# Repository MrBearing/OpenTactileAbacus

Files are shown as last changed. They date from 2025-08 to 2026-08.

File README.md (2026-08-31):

# OpenTactileAbacus

A 3D-printable abacus designed for visually impaired users.

[日本語版README](README_jp.md) | [Thingiverse](https://www.thingiverse.com/thing:7402750) | [MakerWorld](https://makerworld.com/ja/models/3242916-opentactileabacus-ver-2026#profileId-3674481)

## Product Images

### 23-Digit Abacus

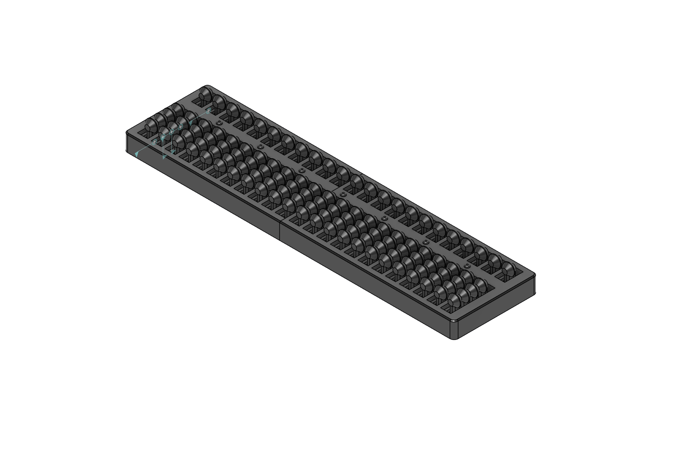
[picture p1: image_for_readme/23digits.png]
Completed 23-digit abacus

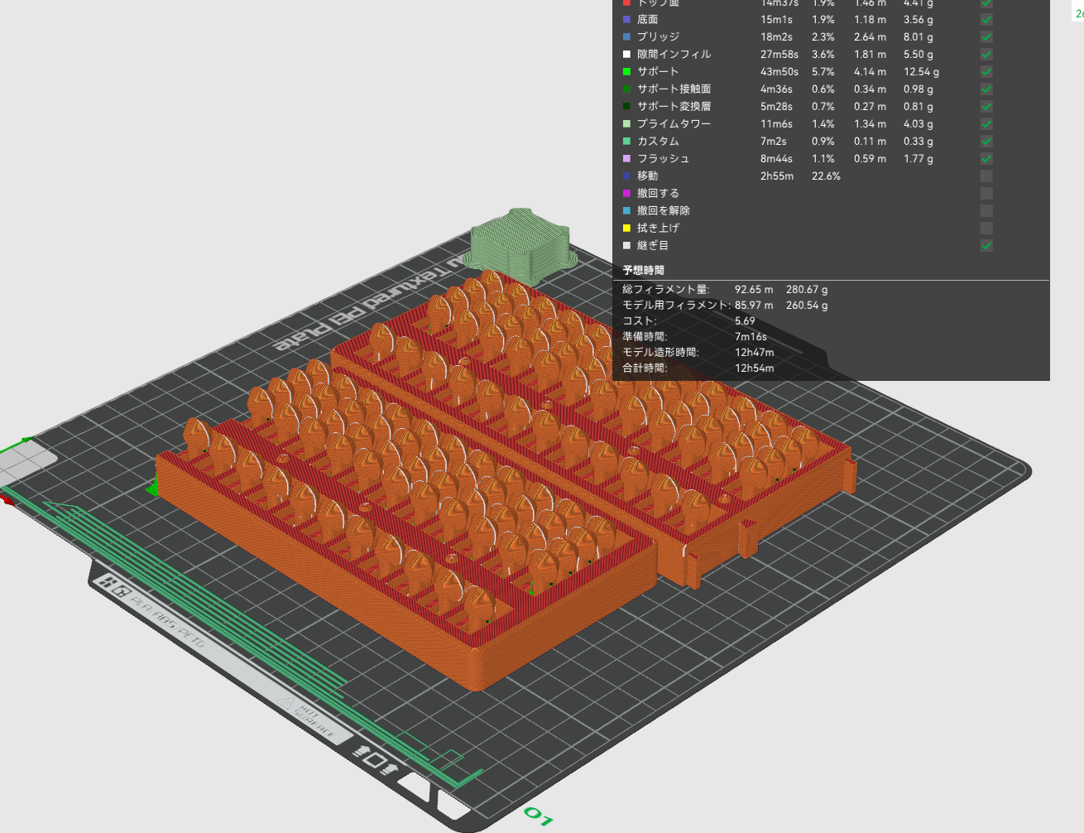
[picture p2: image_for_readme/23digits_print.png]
Printed 23-digit abacus


## Features

- **Tactile-Optimized Design**: Beads and frame designed for fingertip operation by visually impaired users
- **Print-in-Place Model**: The frame and beads are printed together, so the beads do not need to be installed separately
- **Split Frame**: Print the left and right frame sections and join their dovetail connectors to complete the abacus
- **3D-Printable**: Compatible with standard 3D printers

## File Structure

```
├── README.md              # English README (this file)
├── README_jp.md           # Japanese README
├── 3mf/
│   └── 23digits_abacus.3mf          # 23-digit abacus (3MF format)
├── autodesk_fusion/
│   ├── 23digits_abacus.f3z          # Source file (Fusion 360)
│   └── 23digits_abacus.step         # Exchange CAD file (STEP format)
└── stl/
    ├── 23digits_abacus_left.stl     # Left section of the 23-digit abacus (STL format)
    └── 23digits_abacus_right.stl    # Right section of the 23-digit abacus (STL format)
```

## Available Models

### 23-Digit Abacus

- **3MF File (Recommended)**: `3mf/23digits_abacus.3mf`
- **STL Files**:
  - `stl/23digits_abacus_left.stl`
  - `stl/23digits_abacus_right.stl`

### Source Files

Fusion 360 source files are provided for customization and improvement:

- `autodesk_fusion/23digits_abacus.f3z`
- `autodesk_fusion/23digits_abacus.step`

## Print Specifications

### Tested Print Environment

- **3D Printer**: Bambu Lab X1 Carbon
- **Other Compatible Printers**:
  - Standard FDM 3D printers with a 0.4 mm nozzle
  - Printers with a sufficient build volume

### Recommended File Format

- **3MF File (Recommended)**: Includes print settings and supports optimized for Bambu Lab printers
  - The included profile uses **Bambu Support For PLA/PETG as filament 2 for the support interfaces** and sets the top Z distance to `0 mm`. Map filament 2 to the specified support material and use an AMS or an equivalent multi-material setup.
  - Do not map both filament slots to the same PLA spool without first adding a removable interface gap; the zero-gap interfaces may bond to the print-in-place parts.
- **STL Files**: For other printers or custom slicer settings
  - **Important (Bambu Studio)**: Set **Slice gap closing radius** (`slice_closing_radius`) to `0.02 mm` before slicing

### Recommended Settings

- **Layer Height**: 0.2 mm
- **Infill**: 15–20%
- **Supports**: May be required (refer to the layout and settings in the 3MF file)
- **Print Time**:
  - 23-digit version: Approximately 12 hours (one build plate)
- **Filament Usage**:
  - 23-digit version: Approximately 280 g
- **Material**: PLA recommended (ABS and PETG are also supported)

Print time and filament usage are estimates based on the Bambu Lab X1 Carbon.

### Post-Processing

1. Carefully remove the support material.
2. Insert a flat-head screwdriver with an approximately 3 mm-wide tip into the hole at the bottom of each bead. Move the bead back and forth several times to break the bonds formed during printing.

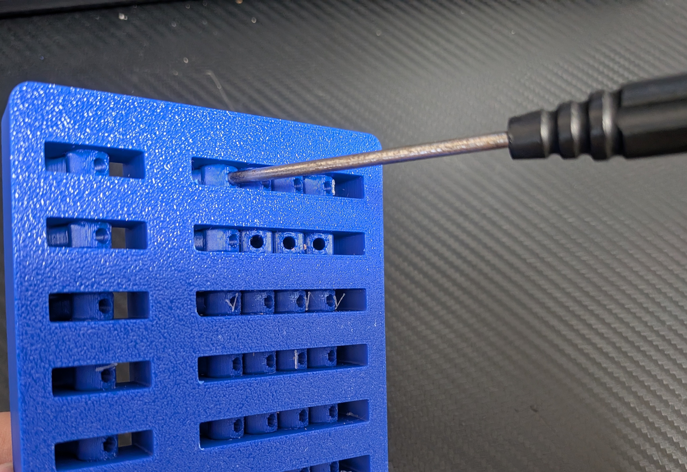
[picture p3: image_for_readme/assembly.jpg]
Using a flat-head screwdriver in the hole at the bottom of a bead to release print bonds
   

3. Check that each bead moves along its rod.
4. If a bead is tight, move it back and forth repeatedly to wear in the sliding surfaces. If it remains tight, lightly sand the rod.
5. Make sure all beads move smoothly and provide comfortable tactile operation for visually impaired users.

> **Caution**: Work carefully and do not apply excessive force, as the screwdriver could damage the printed parts or cause injury.

## Assembly Instructions

### Using the 3MF File (Recommended)

1. Open `3mf/23digits_abacus.3mf` in Bambu Studio and print the left and right sections.
2. Follow the post-processing instructions above to remove supports and release the beads.
3. Join the dovetail connectors on the left and right sections.
4. Confirm that every bead moves smoothly.

### Using the STL Files

1. Import `stl/23digits_abacus_left.stl` and `stl/23digits_abacus_right.stl` into your slicer.
2. If you use Bambu Studio, set **Slice gap closing radius** (`slice_closing_radius`) to `0.02 mm`.
3. Set an appropriate orientation and supports, then print both sections.
4. Follow the post-processing instructions above to remove supports and release the beads.
5. Join the dovetail connectors on the left and right sections.
6. Confirm that every bead moves smoothly and adjust as needed.

## Usage

### Basic Operation

1. Five-value bead (upper bead): Each bead represents 5.
2. One-value beads (lower beads): Each bead represents 1, with four beads per digit representing values up to 4.
3. Move the beads with your fingertips to represent numbers and perform calculations.

## Contributions and Improvements

Contributions to this project are welcome:

- **Issues**: Report bugs or suggest improvements
- **Pull Requests**: Submit design improvements or documentation updates
- **Discussions**: Share user feedback and examples of educational use

## Support and Contact

- **Issues**: Please use the GitHub Issues tab for questions and reports
  - Examples:
    - Requests for different size variations
    - Surface textures that improve tactile identification
    - Better assembly methods
    - Expanded educational guides

- **Discussions**: Exchange information through GitHub Discussions
- **Email**: takumi1988okamoto@gmail.com

## Credits

This project was created to support the education of visually impaired people and promote numeracy learning.

We hope it contributes to a more accessible society.

## Related Links

- [Thingiverse](https://www.thingiverse.com/thing:7402750)
- [MakerWorld](https://makerworld.com/ja/models/3242916-opentactileabacus-ver-2026#profileId-3674481)

## License

This work is licensed under the Creative Commons Attribution 4.0 International License (CC BY 4.0).

© 2025–2026 Takumi Okamoto

See the [LICENSE](LICENSE) file for details.
Please also read the [Disclaimer](DISCLAIMER.md) before use.

---

**We hope this project makes a meaningful contribution to the learning and daily lives of visually impaired people.**

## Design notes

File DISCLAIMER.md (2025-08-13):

# Disclaimer / 免責事項

## English

### General Disclaimer
The creator of OpenTactileAbacus assumes no responsibility for patent infringement, other intellectual property right infringement, product liability, or any other damages arising from the use of this data (including commercial use and modifications). Users are obligated to verify and comply with relevant laws, safety standards, and third-party rights at their own responsibility.

### Commercial Use Notice
Those engaging in commercial use should conduct independent patent research and legal risk assessment before use. Users are responsible for obtaining necessary rights clearances and ensuring product safety and quality control.

### Patent Notice
The creator's patent research is limited and does not cover all relevant patents. Users are responsible for conducting comprehensive patent research before use.

### Safety Notice
This design is intended for educational and personal use. Users must ensure that printed products meet applicable safety standards, especially when used by children or in educational settings.

### No Warranty
This work is provided "as is" without warranty of any kind, either express or implied, including but not limited to the warranties of merchantability, fitness for a particular purpose, and non-infringement.

---

## 日本語

### 一般免責事項
OpenTactileAbacusの制作者は、本データの使用（商業利用、改変を含む）により生じた特許権侵害、その他の知的財産権侵害、製造物責任、および一切の損害について責任を負いません。使用者は自己責任において、関連する法令、安全基準、第三者の権利を確認し、遵守する義務を負います。

### 商業利用時の注意事項
商業利用を行う者は、使用前に独自に特許調査および法的リスク評価を実施することを推奨します。使用者は必要な権利処理を行い、製品の安全性確保および品質管理について責任を負います。

### 特許に関する注意事項
制作者による特許調査は限定的であり、すべての関連特許を網羅するものではありません。使用者は使用前に包括的な特許調査を行うことを推奨します。

### 安全に関する注意事項
本設計は教育用および個人使用を想定しています。使用者は印刷された製品が適用される安全基準を満たすことを確認する必要があります。特に子供や教育現場での使用時は注意が必要です。

### 無保証
本作品は「現状のまま」提供され、商品性、特定目的への適合性、非侵害性を含むがこれらに限定されない、明示または黙示の保証は一切ありません。

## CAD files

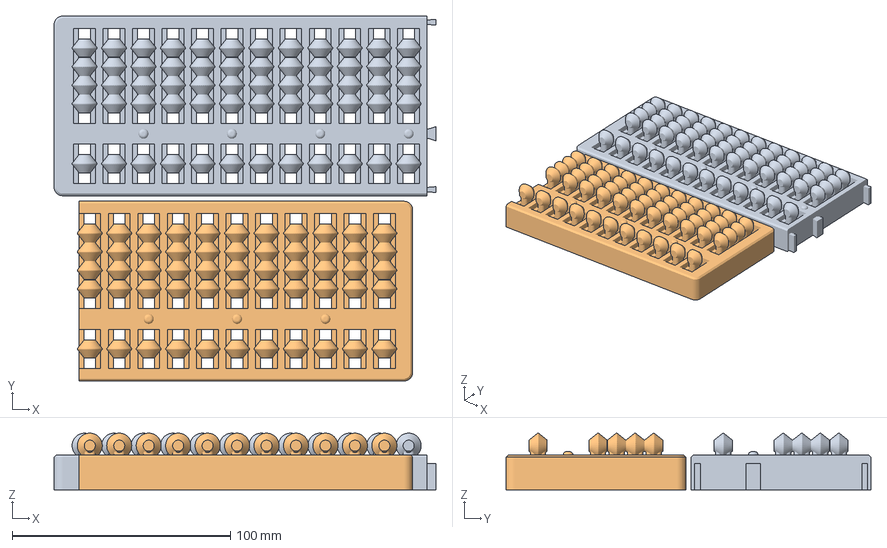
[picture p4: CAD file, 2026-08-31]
3mf/23digits_abacus.3mf
175.0 x 167.3 x 26.0 mm
23digits_abacus_right.
23digits_abacus_left

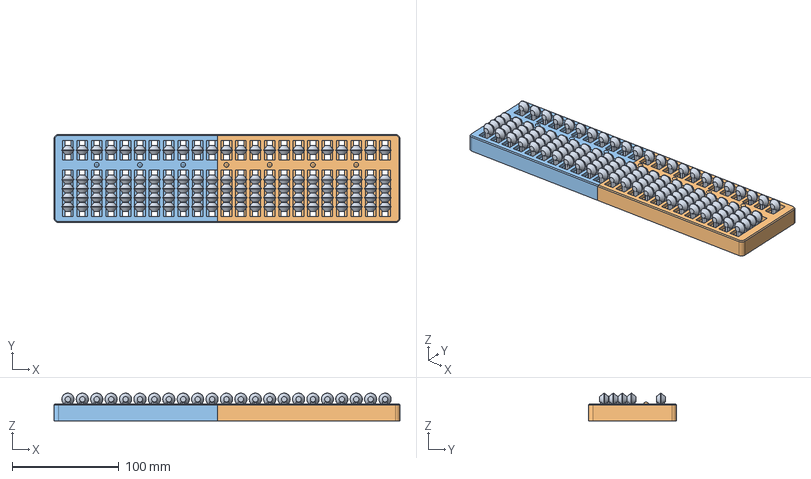
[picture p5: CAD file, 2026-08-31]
autodesk_fusion/23digits_abacus.step
324.0 x 82.4 x 26.0 mm
コマ13㎜ x 115

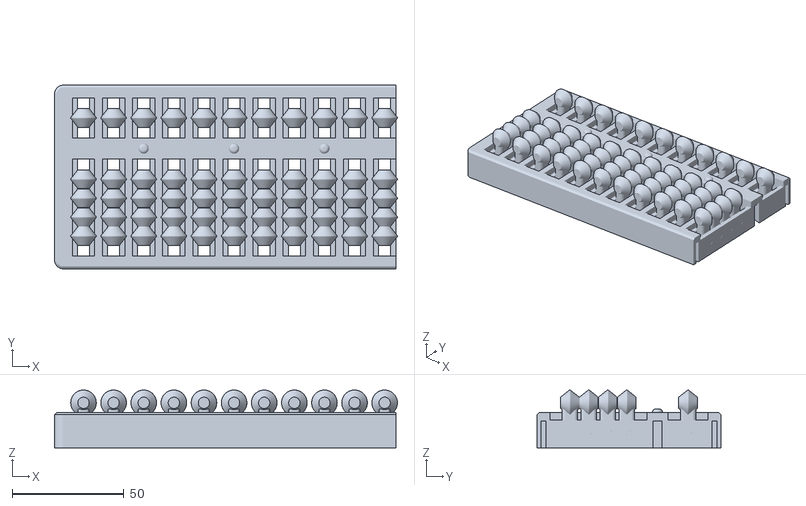
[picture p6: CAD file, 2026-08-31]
stl/23digits_abacus_left.stl
153.7 x 82.4 x 26.0

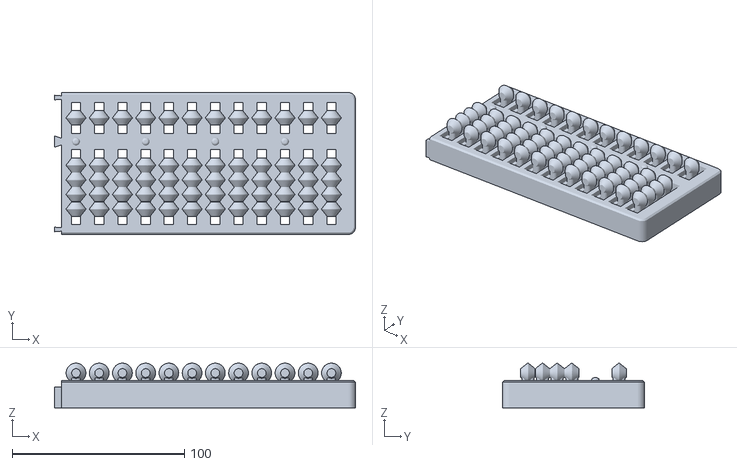
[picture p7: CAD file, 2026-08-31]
stl/23digits_abacus_right.stl
175.0 x 82.4 x 26.0

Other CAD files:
autodesk_fusion/23digits_abacus.f3z
